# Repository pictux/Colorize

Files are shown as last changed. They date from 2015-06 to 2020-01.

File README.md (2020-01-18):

#Colorize
modulo Colorize

**Colorize** è una installazione interattiva che permette di capire, giocando, il funzionamento di Arduino, vernice conduttiva, sensori capacitivi e led strip RGB: tutti i componenti sono in bella vista e corredati da descrizione. 
Il visitartore è invitato a interagire grazie a tre antenne che fungono da sensori di prossimità: muovendo le mani sopra di esse può variare la gradazione delle componenti Rosso, Verde e Blu della lampada realizzata con la strip led RGB.

//

Colorize is an interactive installation that allows to learn (by playing) how Arduino, conductive paint, capacitive sensor and RGB led strip work: all the electronics components and wiring are exposed and described.
Visitors are invited to interact with the installation using 3 "antennas" (made with conductive paint) that act as proximity sensors: moving their hands on these, it's possible to change the Red, Green and Red components on the lamp

###Componenti // BOM:
- Arduino UNO (http://bit.ly/ArduUNO)

Arduino UNO

- Adafruit MPR121 Breakout Board (http://bit.ly/AdaMPR121)

Adafruit MPR121 Breakout Board

- Grove RGB Driver (http://bit.ly/SeeedRGBr)

Grove RGB Driver

- Strip LED RGB 12V con copertura // with case

RGB StripCase

- Vernice e Gel conduttivi // Conductive Paint & Gel (http://bit.ly/BConductive)

BareConductive

##Codice // Code
Il codice è disponibile nella cartella "Arduino". 
I modelli 3d delle parti in plastica sono disponibili nella cartella "STL"
C'è anche un codice in Processing per testate la sensibilità delle antenne, nella cartella "Processing".

//

Code is available in the "Arduino" folder.
3d models of the plastic parts are available in the "STL" folder.
In the folder "Processing" there is a Processing code to test the proximity sensors.

##Interazione // Interaction
Interactions TedX Padova 2015

##Dietro le quinte // Backstage
Gloria & Bare Conductive

Altre foto (backstage e interazioni) // Photo Gallery (backstage & interactions): 

http://bit.ly/Colorize_Gallery

##Credits
Concept, Design HW & SW : Gloria Spagnolo & Mirco Piccin @ Xuni

Graphic Design : Tiziano Maffione

Vinil Cutting & Placement, Stencils : Marco Filippi @ ImageCar

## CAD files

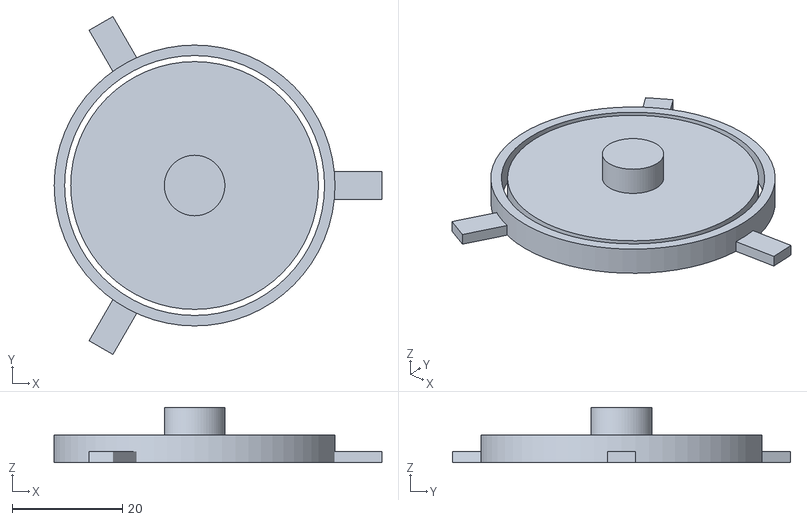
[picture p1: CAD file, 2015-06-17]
STL/roll_top_support.stl
59.5 x 61.4 x 10.0

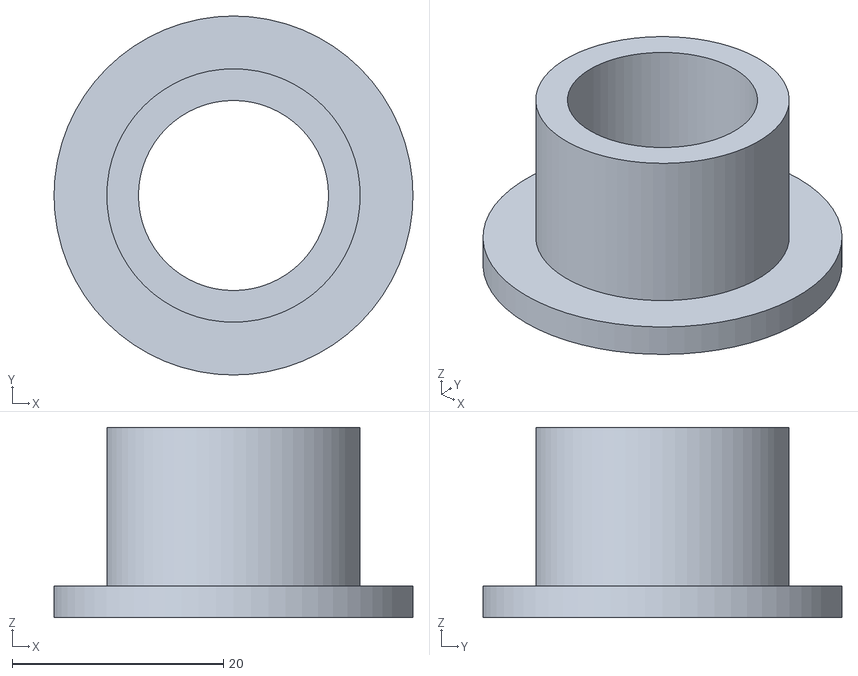
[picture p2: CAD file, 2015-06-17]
STL/wiring_hole.stl
34.0 x 34.0 x 18.0

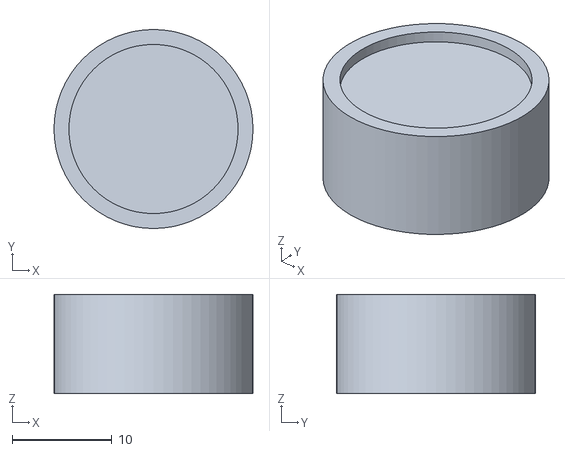
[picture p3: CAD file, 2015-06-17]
STL/foot.stl
20.0 x 20.0 x 10.0

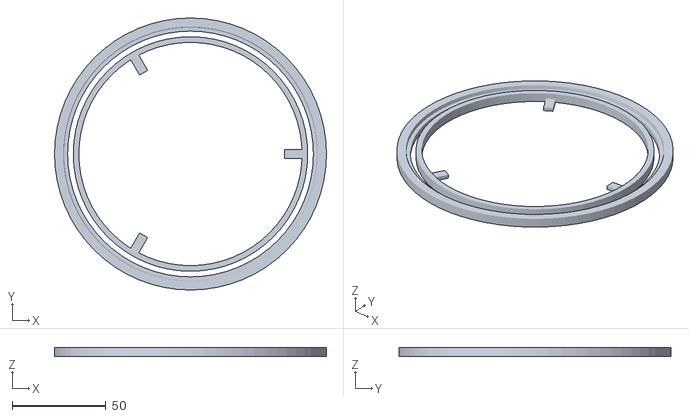
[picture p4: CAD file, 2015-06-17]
STL/cakebox_supports.stl
145.0 x 145.0 x 5.00

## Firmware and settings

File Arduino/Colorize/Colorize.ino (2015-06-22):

/*
  Colorize is an interactive installation that allows to learn (by playing) how Arduino, 
  conductive paint, capacitive sensor and RGB led strip work.
  Project description / images / code : 
  https://github.com/pictux/Colorize 
  
  Based on :
  - Bare Conductive Proximity MP3 player, code by Jim Lindblom and plenty of inspiration from the Freescale 
  Semiconductor datasheets and application notes
  - LedDriver example code by Frankie Chu/Grove/Seeedstudio
    
  This work is licensed under a Creative Commons Attribution-ShareAlike 3.0 
  Unported License (CC BY-SA 3.0) http://creativecommons.org/licenses/by-sa/3.0/
*/

#include "RGBdriver.h"
#include <MPR121.h>
#include <Wire.h>

#define MPR121_ADDR 0x5A

#define CLK 2//pins definitions for the driver        
#define DIO 3

// mapping and filter definitions
#define LOW_DIFF 0
#define HIGH_DIFF 50
#define filterWeight 0.3f // 0.0f to 1.0f - higher value = more smoothing
float lastProx3 = 0;
float lastProx6 = 0;
float lastProx9 = 0;

// the electrodes to monitor for proximity
#define PROX_ELECTRODE3 3
#define PROX_ELECTRODE6 6
#define PROX_ELECTRODE9 9

#define LED_BUILTIN 13

RGBdriver Driver(CLK, DIO);

//#define VERBOSE

void setup() {
  Serial.begin(9600);

  pinMode(LED_BUILTIN, OUTPUT);

  //while (!Serial) ; {} //uncomment when using the serial monitor
#ifdef VERBOSE
  Serial.println("Bare Conductive Touch MP3 player");
#endif
  if (!MPR121.begin(MPR121_ADDR)) Serial.println("error setting up MPR121");
  //MPR121.setInterruptPin(MPR121_INT);

  // slow down some of the MPR121 baseline filtering to avoid
  // filtering out slow hand movements
  MPR121.setRegister(NHDF, 0x01); //noise half delta (falling)
  MPR121.setRegister(FDLF, 0x3F); //filter delay limit (falling)
}

void loop() {
  readTouchInputs();
}


void readTouchInputs() {

  MPR121.updateAll();

  for (int i = 1; i < 12; i++) { // Check which electrodes were pressed
    if (MPR121.isNewTouch(i)) {
#ifdef VERBOSE
      //pin i was just touched
      Serial.print("pin ");
      Serial.print(i);
      Serial.println(" was just touched");
      digitalWrite(LED_BUILTIN, HIGH);
#endif

    } else {
      if (MPR121.isNewRelease(i)) {
#ifdef VERBOSE
        Serial.print("pin ");
        Serial.print(i);
        Serial.println(" is no longer being touched");
        digitalWrite(LED_BUILTIN, LOW);
#endif
      }
    }
  }

  // read the difference between the measured baseline and the measured continuous data
  int reading3 = MPR121.getBaselineData(PROX_ELECTRODE3) - MPR121.getFilteredData(PROX_ELECTRODE3);
  int reading6 = MPR121.getBaselineData(PROX_ELECTRODE6) - MPR121.getFilteredData(PROX_ELECTRODE6);
  int reading9 = MPR121.getBaselineData(PROX_ELECTRODE9) - MPR121.getFilteredData(PROX_ELECTRODE9);

  // constrain the reading between our low and high mapping values
  unsigned int prox3 = constrain(reading3, LOW_DIFF, HIGH_DIFF);
  unsigned int prox6 = constrain(reading6, LOW_DIFF, HIGH_DIFF);
  unsigned int prox9 = constrain(reading9, LOW_DIFF, HIGH_DIFF);

  // implement a simple (IIR lowpass) smoothing filter
  lastProx3 = (filterWeight * lastProx3) + ((1 - filterWeight) * (float)prox3);
  lastProx6 = (filterWeight * lastProx6) + ((1 - filterWeight) * (float)prox6);
  lastProx9 = (filterWeight * lastProx9) + ((1 - filterWeight) * (float)prox9);

  // map the LOW_DIFF..HIGH_DIFF range to 0..254 (max range for RGB channels)
  uint8_t thisOutput3 = (uint8_t)map(lastProx3, LOW_DIFF, HIGH_DIFF, 0, 254);
  uint8_t thisOutput6 = (uint8_t)map(lastProx6, LOW_DIFF, HIGH_DIFF, 0, 254);
  uint8_t thisOutput9 = (uint8_t)map(lastProx9, LOW_DIFF, HIGH_DIFF, 0, 254);

#ifdef VERBOSE
  Serial.print("Proximity electrode: ");
#endif

  Serial.print(thisOutput3);
  Serial.print(";");
  Serial.print(thisOutput6);
  Serial.print(";");
  Serial.print(thisOutput9);
  Serial.println(";");

  Driver.begin();
  Driver.SetColor(thisOutput3, thisOutput6, thisOutput9);
  Driver.end();
}

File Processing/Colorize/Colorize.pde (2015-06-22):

 /*
  Colorize is an interactive installation that allows to learn (by playing) how Arduino, 
  conductive paint, capacitive sensor and RGB led strip work.
  Project description / images / Arduino code : 
  https://github.com/pictux/Colorize 
  
  This is a simple sketch to test Arduino & proximity sensors 
    
  This work is licensed under a Creative Commons Attribution-ShareAlike 3.0 
  Unported License (CC BY-SA 3.0) http://creativecommons.org/licenses/by-sa/3.0/
*/

import processing.serial.*;

Serial myPort;  // Create object from Serial class
float red, green, blue;
String longValue = ""; 


void setup() 
{
  size(500, 480);
  // Open whatever port is the one you're using (COMx on Windows, /dev/tty.usbmodem on Mac, /dev/ttyACMx on Linux).
  String portName = "/dev/ttyACM0"; 
  myPort = new Serial(this, portName, 9600);
  myPort.bufferUntil('\n');
}

void draw()
{
  //the background color is defined by the value received from Serial Port
  background(red, green, blue);
  
  rect(((width / 4)) -20, height - 120, 40, - (red*2));
  rect(((width / 4) * 2) -20, height - 120, 40, - (green*2));
  rect(((width / 4) * 3) -20, height - 120, 40, - (blue*2));
}

void serialEvent(Serial p)
{
  longValue = myPort.readString();
  
  red = float(longValue.split(";")[0]);
  green = float(longValue.split(";")[1]);
  blue = float(longValue.split(";")[2]);

  print(red);
  print(";");
  println(green);
  print(";");
  println(blue); 
}

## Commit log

2015-06-17 Added STL files #1
    [cakebox_support.stl, foot.stl, roll_top.stl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]
2015-06-17 Added STL files #2
    [cakebox_supports.stl, roll_top_support.stl]
2015-06-17 Deleted STL files #1
    [cakebox_support.stl, roll_top.stl]
2015-06-22 Arduino & Processing files added
